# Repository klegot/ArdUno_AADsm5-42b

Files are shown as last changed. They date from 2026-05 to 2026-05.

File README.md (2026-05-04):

# Проектирование Arduino Uno в Altium Designer

Репозиторий содержит материалы учебного цикла из 8 лабораторных работ по курсу **«Конструирование приборов»**. В рамках проекта осуществляется воссоздание платы **Arduino Uno** с адаптацией под стандарты **ГОСТ/ЕСКД**.

## 🎯 Цель лабораторных работ
Пройти полный цикл проектирования электронного узла в САПР Altium Designer: от создания библиотек компонентов до генерации производственных файлов.

## 🛠 Технологический стек
* **САПР:** Altium Designer
* **Стандарты:** ГОСТ 2.701-2008, ГОСТ 2.106-1996
* **Компонентная база:** ATMEGA328P-PU и сопутствующая обвязка
---
*Работа выполнена в рамках учебного процесса МГТУ им. Н.Э. Баумана (кафедра СМ5).*

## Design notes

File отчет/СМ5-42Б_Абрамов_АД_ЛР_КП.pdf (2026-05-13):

Москва, 2026

Министерство науки и высшего образования Российской Федерации Федеральное государственное автономное образовательное учреждение высшего образования
«Московский государственный технический университет имени Н.Э. Баумана
(национальный исследовательский университет)» (МГТУ им. Н.Э. Баумана)
ФАКУЛЬТЕТ | Специальное машиностроение
КАФЕДРА | Автономные информационные и управляющие системы

### ОТЧЕТ ПО ЛАБОРАТОРНЫМ РАБОТАМ По курсу: «Конструирование приборов»

Группа: | СМ5-42б
Студент | Абрамов А.Д.
дата сдачи работы | подпись | фамилия, и.о.
Преподаватель | Воробьев А.К.
| подпись | фамилия, и.о.

### 1 Основные пункты выполнения работы

В рамках данного курса требуется создать проект, включающий схемную

библиотеку компонентов, библиотеку посадочных топологических мест

компонентов (ПТМ), электрическую принципиальную схему устройства,

трассировку печатной платы. Также создать выходную документацию для

производства (гербер-файлы, файлы сверловки, перечень элементов, 3D-модель

платы). Все действия проводятся в соответствии с ГОСТ, проект повторяет

Arduino Uno, порядок действий:

- Разработка библиотек компонентов: создание УГО и ПТМ

микросхемы ATMEGA328P-PU,

- Разработка библиотек компонентов: создание УГО и ПТМ

микросхемы ATMEGA16U2-MU,

- Разработка библиотек компонентов: создание УГО и ПТМ для

резистора, варистора, предохранителя, конденсатора, диода, светодиода и

кварцевого резонатора,

- Разработка библиотек компонентов: создание УГО и ПТМ для

разъемов, микросхемы ОУ, микросхемы линейного стабилизатора напряжения,

индуктивности, полевого транзистора и кнопочного переключателя,

- Создание электрической принципиальной схемы: подключение

форматки, отрисовка электрической принципиальной схемы, проверка схемы на

наличие ошибок, формирование перечня компонентов, экспорт схемы в PDF,

- Размещение компонентов на печатной плате: импорт компонентов на

ПП, задание геометрических размеров ПП, стадии размещения компонентов на

- ПП, размещение компонентов на ПП, 3D-вид ПП,
- Подготовка к трассировке печатной платы: настройка правил

проектирования, импорт/экспорт правил проектирования, настройка структуры

слоев ПП, настройка редактора ПП,

- Трассировка печатной платы: трассировка сигнальных линий,

трассировка питания и земли, заливка полигонов, оптимизация расположения проводников, отладка ошибок трассировки, установка реперных знаков,

формирования файлов для производства.

### 2 Создание проекта в Altium Designer и разработка библиотек

компонентов

В Altium Designer создан проект ArdUno_AADsm5-42b_ver1.1, в него

добавлены файлы схемной библиотеки, библиотеки посадочных мест, схемы и

печатной платы (Рисунок 1).

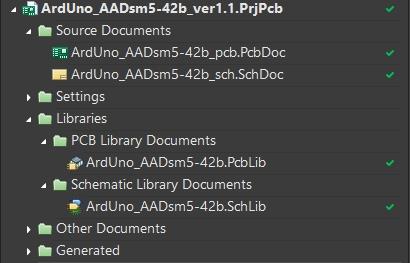
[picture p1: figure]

Рисунок 1 – Рабочая директория проекта и его содержание

В процессе проектирования и подготовки изделия к изготовлению для

каждого элемента необходимо создать несколько представлений: условное

графическое обозначение (УГО) и посадочное топологическое место (ПТМ) для

печатной платы (Footprint). ПТМ включает в себя конфигурацию контактных

площадок (КП) и контур корпуса детали с регламентированными габаритами,

которые берутся из технической документации (Datasheet) на конкретное

изделие. ПТМ задает точную область на плате, необходимую для установки,

фиксации и электрического подключения физического элемента. Алгоритм

создания посадочных мест продемонстрирован на примере базовой группы

компонентов, тогда как для остальных деталей операции выполняются по

аналогичной схеме.

Создано УГО микросхемы ATMEGA328P-PU. В файле схемной

библиотеки, в панели SCH Library добавлен новый компонент кнопкой Add.

Настроено окно свойств компонента (Рисунок 2), знак «?» в поле Designator

необходим Altium для последующей автоматической нумерации компонентов на

схеме, заданы соответствующие параметры создаваемого элемента.

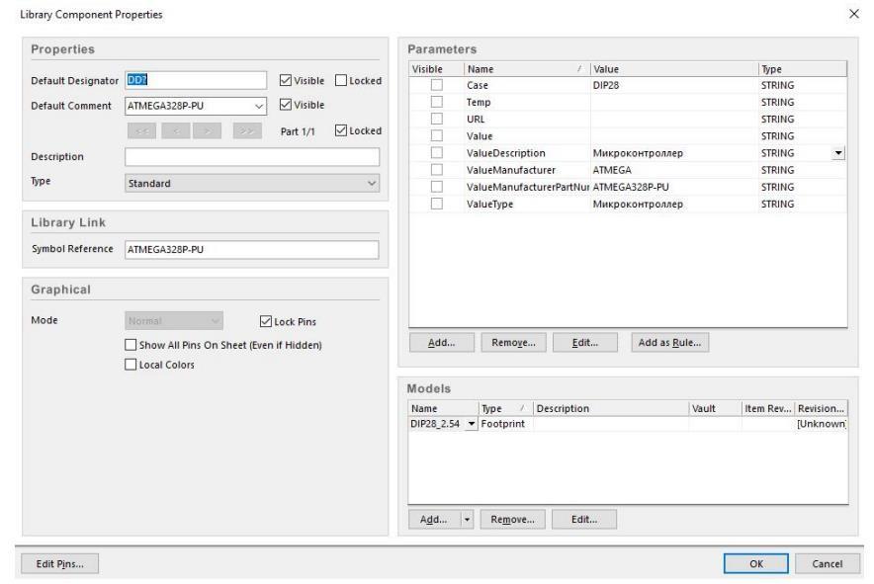
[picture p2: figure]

Рисунок 2 – Окно настройки свойств компонента схемной библиотеки

Начерчены границы корпуса в виде прямоугольника 50х135 мм и

вертикальные линии, отделяющие основное поле для подписей от двух

дополнительных, на расстоянии 10 мм друг от друга, затем размещены все 28

выводов микросхемы согласно документации, добавлены подписи (Рисунок 3).

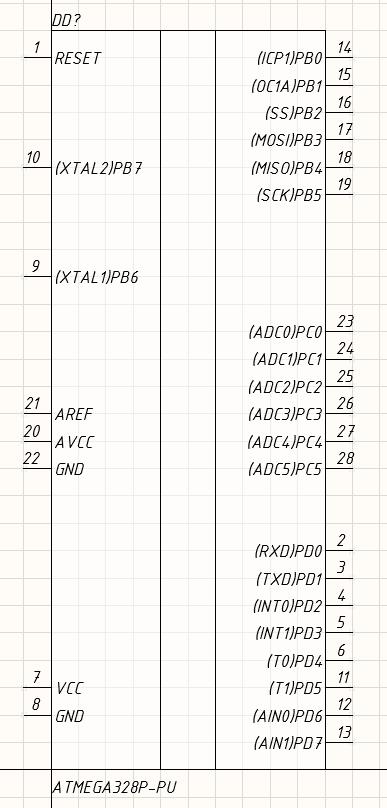
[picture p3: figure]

Рисунок 3 – УГО микросхемы ATMEGA328P-PU

Создано ПТМ микросхемы ATMEGA328P-PU в соответствии с

технической документацией (Рисунок 4) с помощью мастера создания ПТМ, где

выбраны параметры:

- тип корпуса: DIP,
- диаметр КП и отверстий: 1,8 мм и 1,1 мм соответственно,
- расположение КП: 7,62 мм между рядами и 2,54 мм между

элементами одного ряда,

- количество выводов: 28,
- имя создаваемого компонента: DIP28_2.54.

Рисунок 4 – Фрагмент datasheet микросхемы ATMEGA328P-PU с

геометрическими размерами

С помощью шелкографии заданы границы компонента и отмечено

положение 1 вывода микросхемы, результат работы представлен на Рисунке 5.

Рисунок 5 – ПТМ микросхемы ATMEGA328P-PU

Создание ПТМ завершено добавлением к нему 3D-модели корпуса

микросхемы (Рисунок 6).

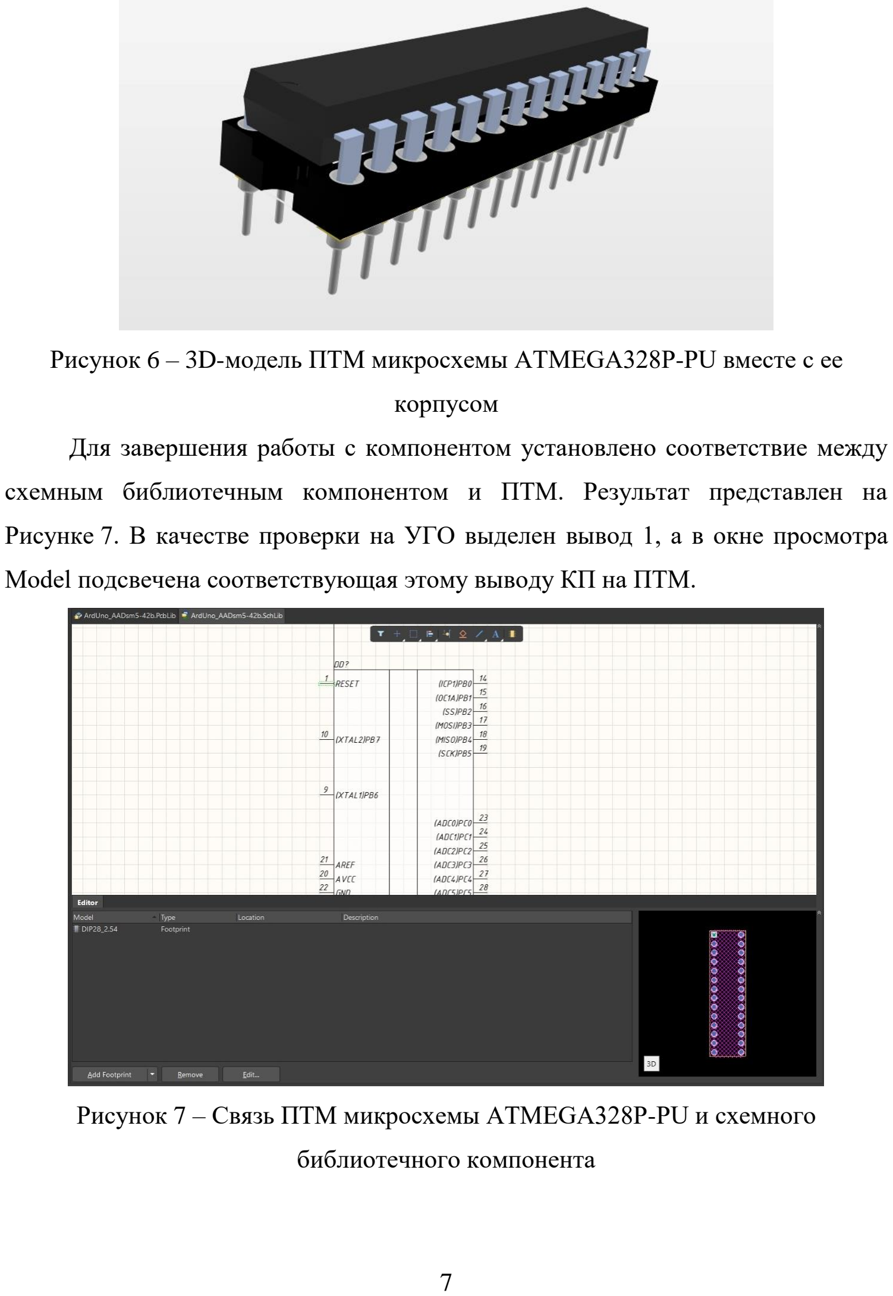
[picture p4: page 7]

Рисунок 6 – 3D-модель ПТМ микросхемы ATMEGA328P-PU вместе с ее

корпусом

Для завершения работы с компонентом установлено соответствие между

схемным библиотечным компонентом и ПТМ. Результат представлен на

Рисунке 7. В качестве проверки на УГО выделен вывод 1, а в окне просмотра

Model подсвечена соответствующая этому выводу КП на ПТМ.

Рисунок 7 – Связь ПТМ микросхемы ATMEGA328P-PU и схемного

библиотечного компонента

Создано УГО конденсатора в схемной библиотеке компонентов. Добавлен

новый компонент и его параметры аналогично предыдущему компоненту. Далее,

было начерчено УГО конденсатора, соответствующее УГО данному в журнале

Радио (№3, 2003 год, стр. 40), приведенное на Рисунке 8. Полученное УГО

конденсатора с добавленными двумя выводами приведено на Рисунке 9.

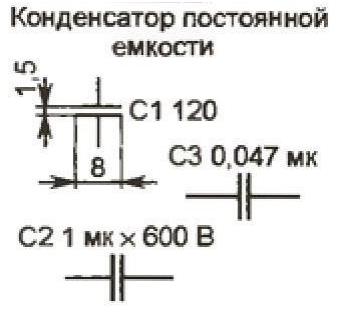
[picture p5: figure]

Рисунок 8 УГО конденсатора из журнала Радио (№3, 2003 год, стр. 40)

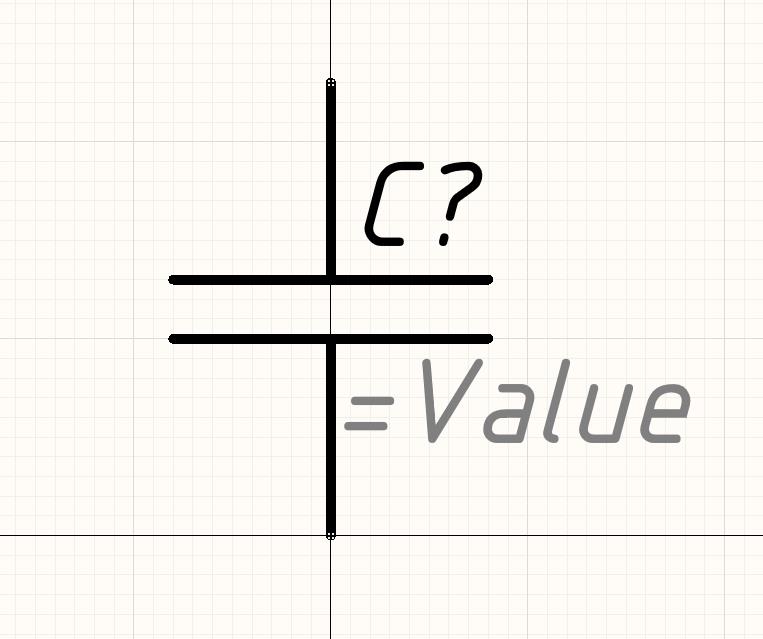
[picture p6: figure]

Рисунок 9 – УГО конденсатора

Создано ПТМ конденсатора. В проекте использован тип неполярных

конденсаторов SMD и типоразмер 0603, использованы параметры ПТМ для

пайки методом оплавления (Рисунок 10).

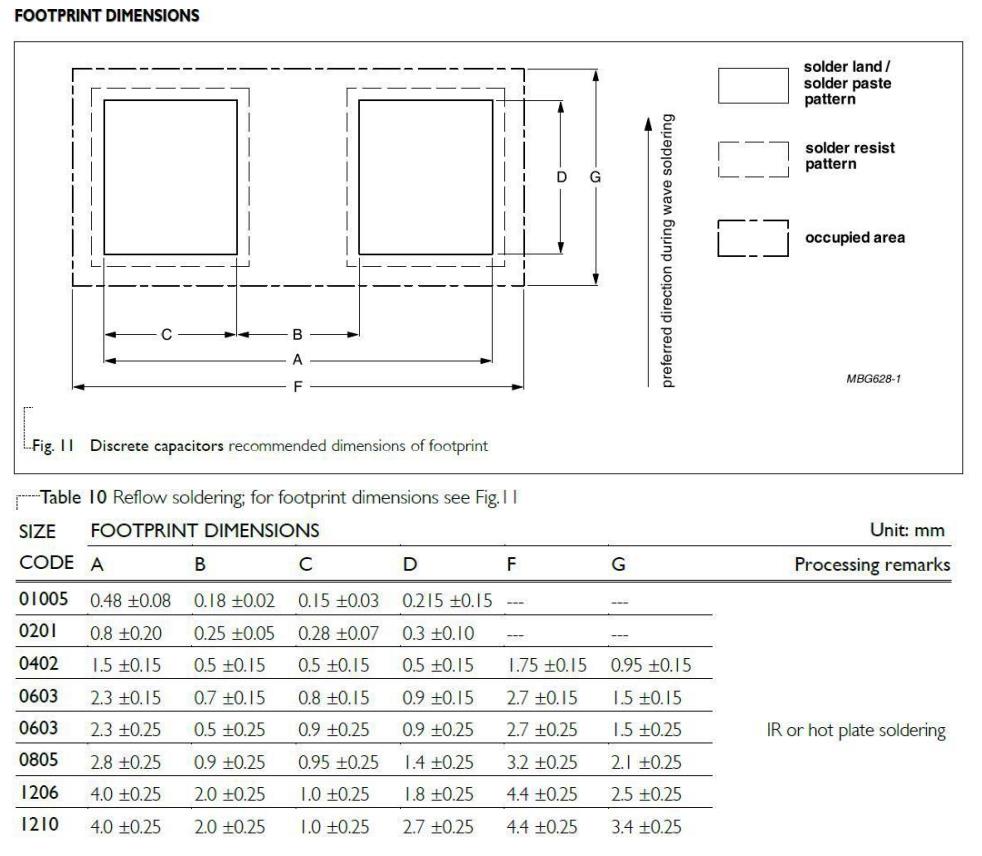
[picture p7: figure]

Рисунок 10 – Геометрические размеры ПТМ для SMD-конденсаторов

На слое Top Layer командой размещения КП Place – Pad размещены на

расстоянии 0,6 мм друг от друга две прямоугольные КП с параметрами

(Рисунок 11):

- размер КП: 0,8х0,9 мм,
- форма КП: Rectangular.

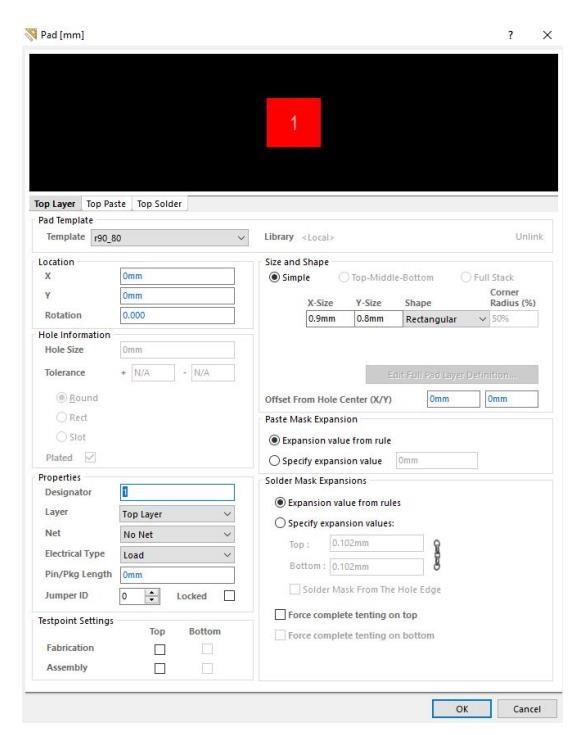
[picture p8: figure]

Рисунок 11 – Диалоговое окно Pad настройки параметров контактной площадки

С помощью шелкографии обозначено положение конденсатора. Результат

создания ПТМ конденсатора представлен на Рисунке 12.

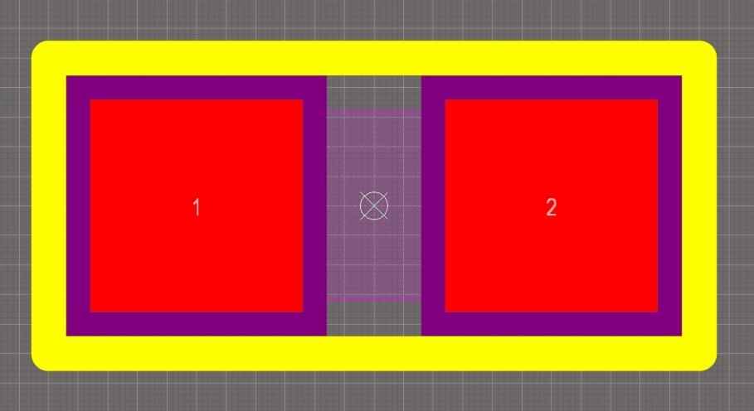
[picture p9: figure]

Рисунок 12 – ПТМ конденсатора

К ПТМ конденсатора прикреплена его 3D-модель (Рисунок 13).

Рисунок 13 – 3D-модель конденсатора на его ПТМ

Установлено соответствие между созданным схемным библиотечным

компонентом и ПТМ конденсатора (Рисунок 14). Аналогично проверена

привязка выводов.

Рисунок 14 – Связь ПТМ конденсатора и схемного библиотечного компонента

### 3 Создание электрической принципиальной схемы и перечня

элементов

На | основании | разработанной | библиотеки | схемных | компонентов

разработана электрическая принципиальная схема устройства Arduino Uno в соответствии с предложенным примером (Рисунок А.1). Размещены компоненты

из схемной библиотеки, выполнены электрические соединения между ними с

помощью команды Place – Wire. Добавлены порты питания и земли с помощью

команды Place – Power Port, затем последние соединены с соответствующими

выводами компонентов, параметры портов настроены в соответствии с ГОСТ

(Рисунки 15, 16).

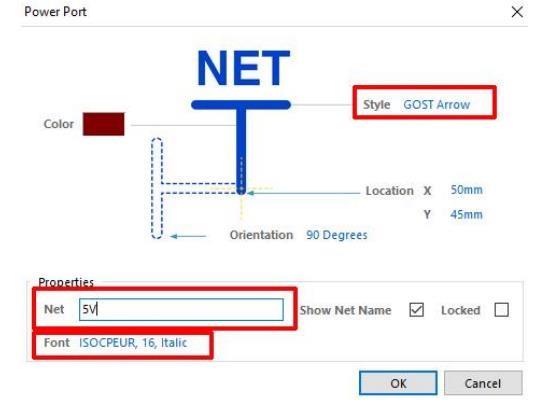
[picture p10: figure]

Рисунок 15 – Диалоговое окно Power Port

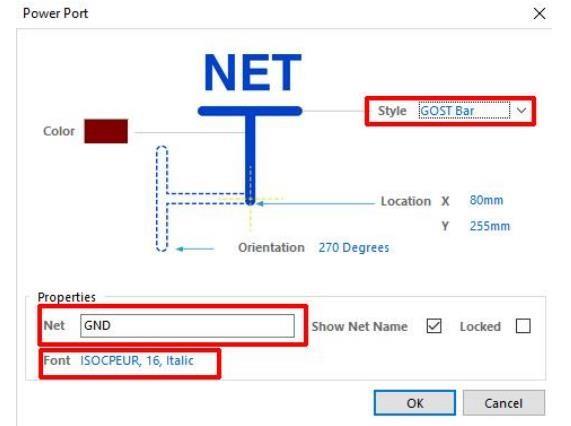
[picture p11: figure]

Рисунок 16 – Диалоговое окно Power Port

После отрисовки электрической принципиальной схемы проведена

нумерация компонентов на схеме с помощью команды Annotate Schematics

(Рисунок 17), схема проверена на наличие ошибок.

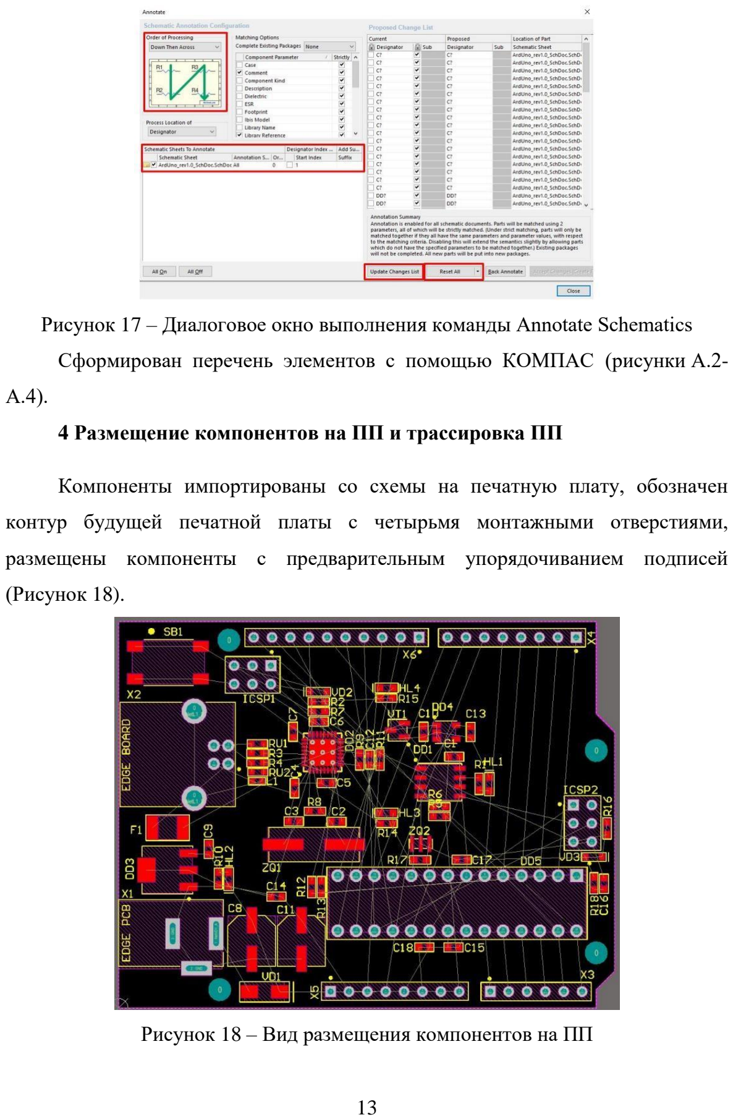
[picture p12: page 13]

Рисунок 17 – Диалоговое окно выполнения команды Annotate Schematics

Сформирован перечень элементов с помощью КОМПАС (рисунки А.2-

А.4).

### 4 Размещение компонентов на ПП и трассировка ПП

Компоненты импортированы со схемы на печатную плату, обозначен

контур будущей печатной платы с четырьмя монтажными отверстиями,

размещены компоненты с предварительным упорядочиванием подписей

(Рисунок 18).

Рисунок 18 – Вид размещения компонентов на ПП

Настроены правила проектирования в соответствии с допустимыми

технологическими возможностями производства, структура слоев, редактор ПП.

Произведена трассировка печатной платы. Все КП, имеющие соединение с

цепью GND соединены с переходными отверстиями, пример приведен на

Рисунке 19.

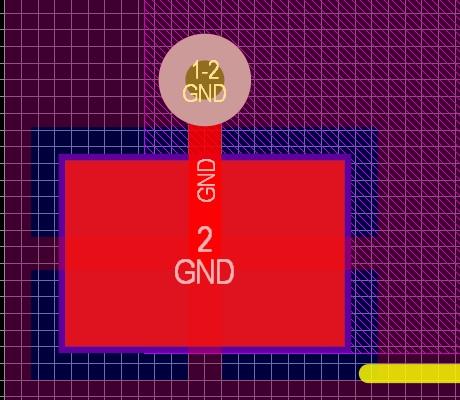
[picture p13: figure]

Рисунок 19 – Размещение переходного отверстия и соединение его с КП

Произведена трассировка длинных сигнальных проводников, коротких

сигнальных проводников, линий питания (ширина проводника увеличена), затем

созданы полигоны земли. С помощью инструмента Design Rule Check

осуществлена проверка топологии ПП, исправлены выявленные ошибки.

Оптимизированы | области | полигонов, | расширено | их | перекрытие, | на

соответствующих участках поставлены переходные отверстия, затем последние

установлены везде, где земляные полигоны верхнего и нижнего слоев

перекрываются (после этого полигоны перезалиты). С помощью инструмента

Design Rule Check снова проведена проверка, исправлены все выявленные

ошибки (Рисунок 20), установлены реперные знаки.

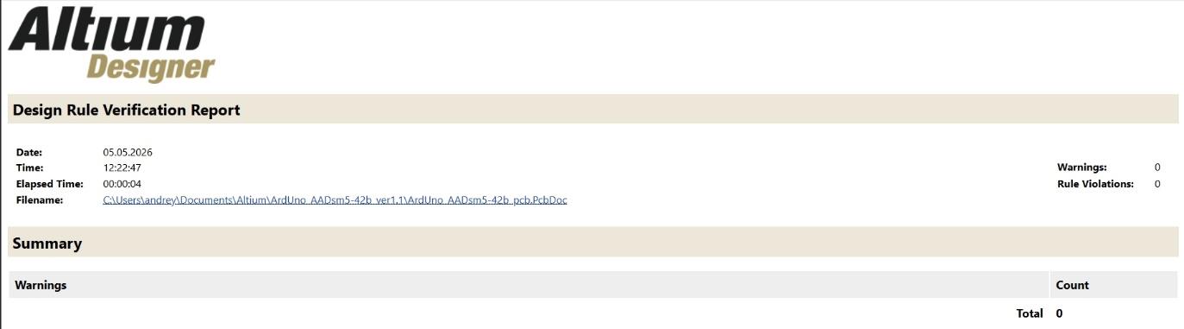
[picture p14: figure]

Рисунок 20 – Отсутствие ошибок проектирования

Оптимизировано | расположение | подписей | компонентов | на | слое

шелкографии, добавлено имя проекта на ПП. В результате проектирования

получена послойная структура печатной платы:

- Top Layer (Рисунок А.5),
- Top Solder (Рисунок А.6),
- Top Overlay (Рисунок А.7),
- Bottom Layer (Рисунок А.8), – Bottom Solder (Рисунок А.9),
- Keep Out Layer (Рисунок А.10).
Для | полного | представления | на | рисунках А.11-А.13 | содержатся

трехмерные изображения разработанной ПП.

Сформированы файлы сверловки (Рисунок А.14) и гербер-файлы

(Рисунки А.15-А.20) для производства.

Таким образом, в рамках учебного проектирования модуля Arduino Uno

были освоены ключевые инструменты среды Altium Designer. Пройден полный

цикл разработки печатной платы, включивший в себя формирование библиотек

компонентов (создание УГО и ПТМ согласно техническим требованиям),

настройку технологических ограничений под требования производства, а также

компоновку элементов на плате. Итогом работы стал завершенный проект

устройства, дополненный файлами для изготовления ПП и комплектом

конструкторской документации по ГОСТ (электрической принципиальной

схемой и перечнем элементов).

ПРИЛОЖЕНИЕ А

В приложение входят:

1) схема электрическая принципиальная (Рисунок А.1);
2) перечень элементов (Рисунки А.2-А.4);
3) послойная структура печатной платы (Рисунки А.5-А.10);
4) трехмерные изображения печатной платы (Рисунки А.11-А.13);
5) файлы сверловки (Рисунок А.14);
6) гербер-файлы (Рисунки А.15-А.20).

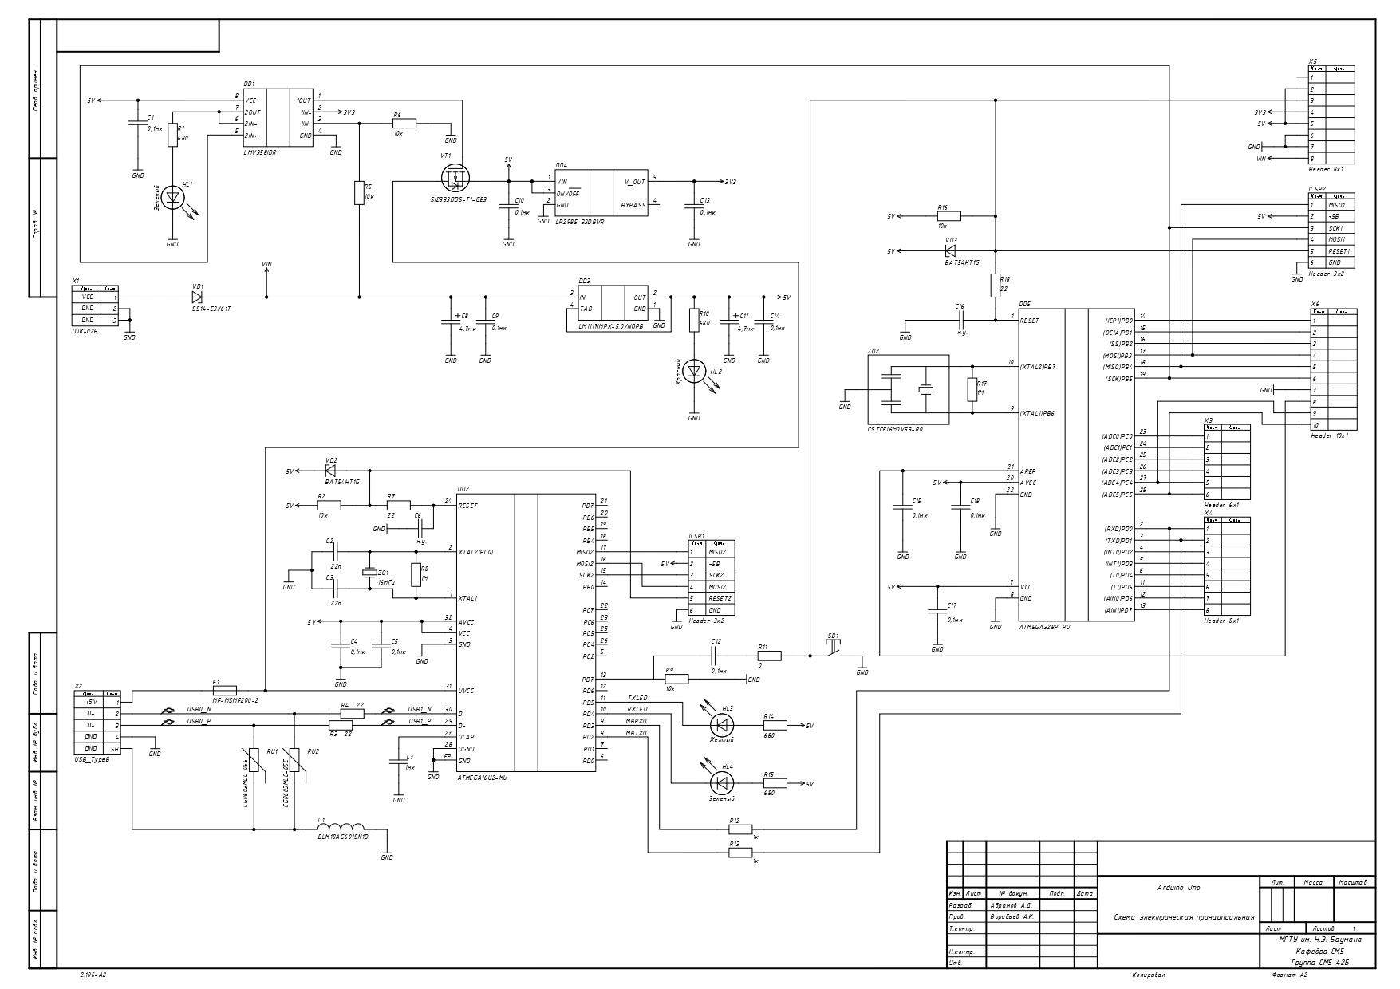
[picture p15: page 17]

Рисунок А.1 – Схема электрическая принципиальная

Москва, 2025 г.

Рисунок А.2 – Перечень элементов, лист 1

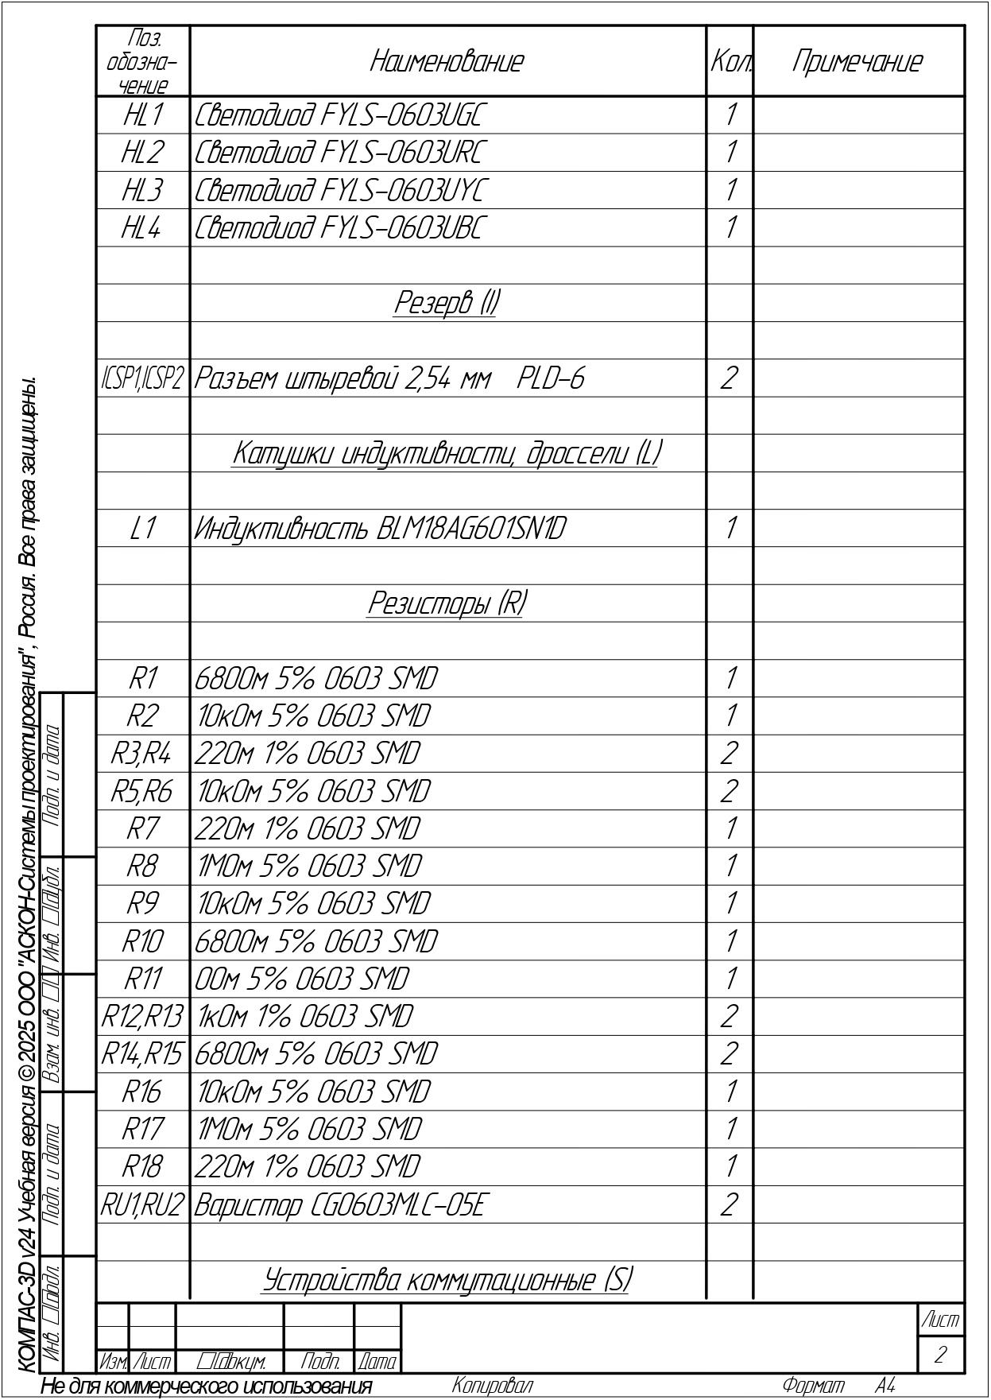
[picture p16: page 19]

Рисунок А.3 – Перечень элементов, лист 2

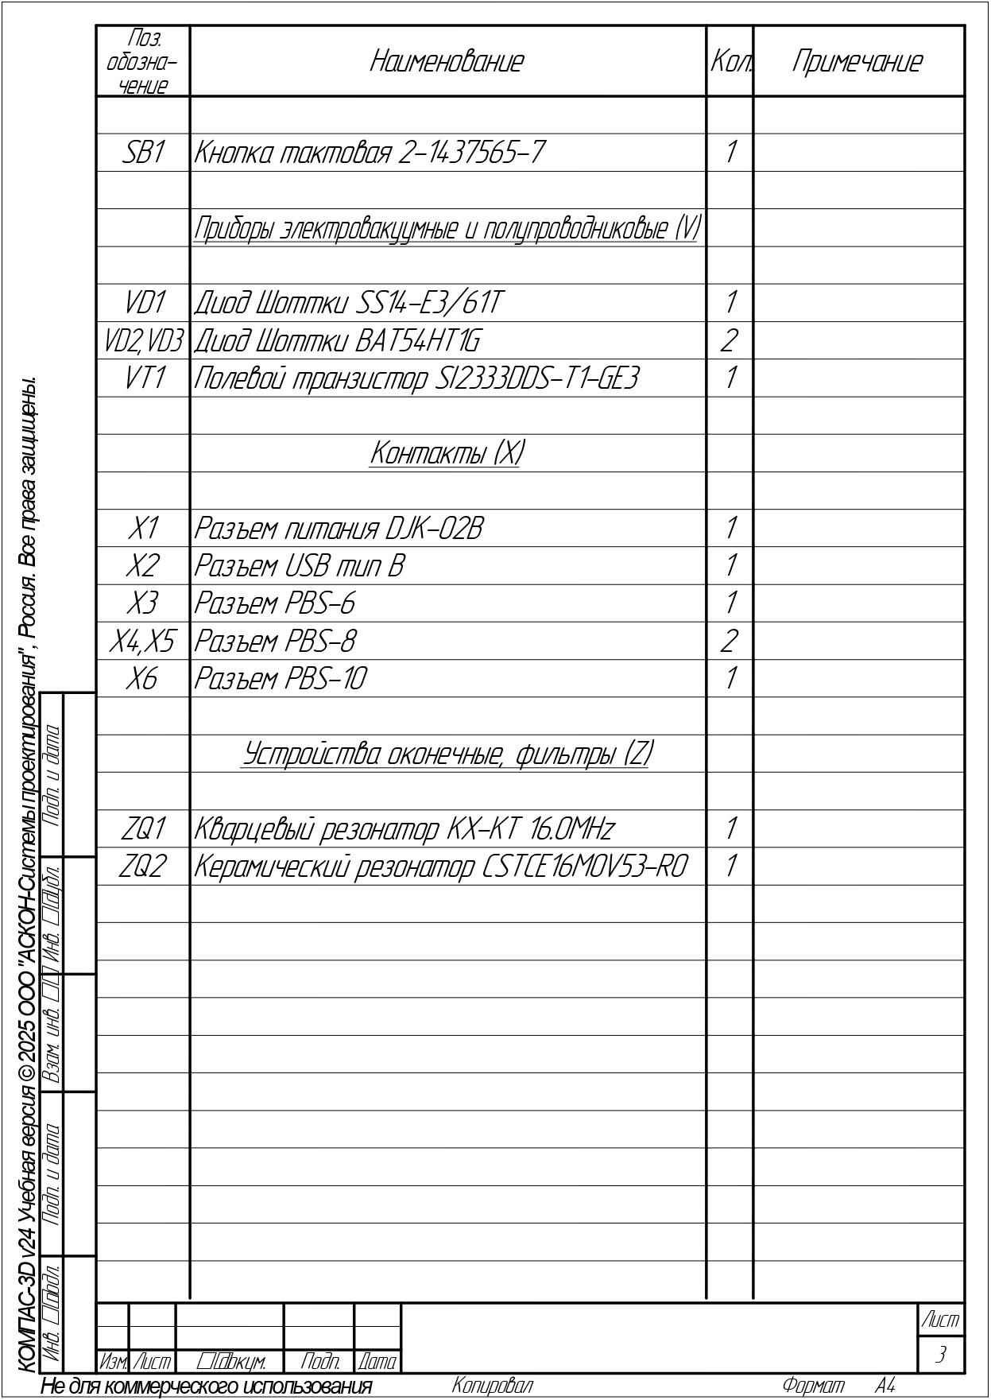
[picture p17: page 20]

Рисунок А.4 – Перечень элементов, лист 3

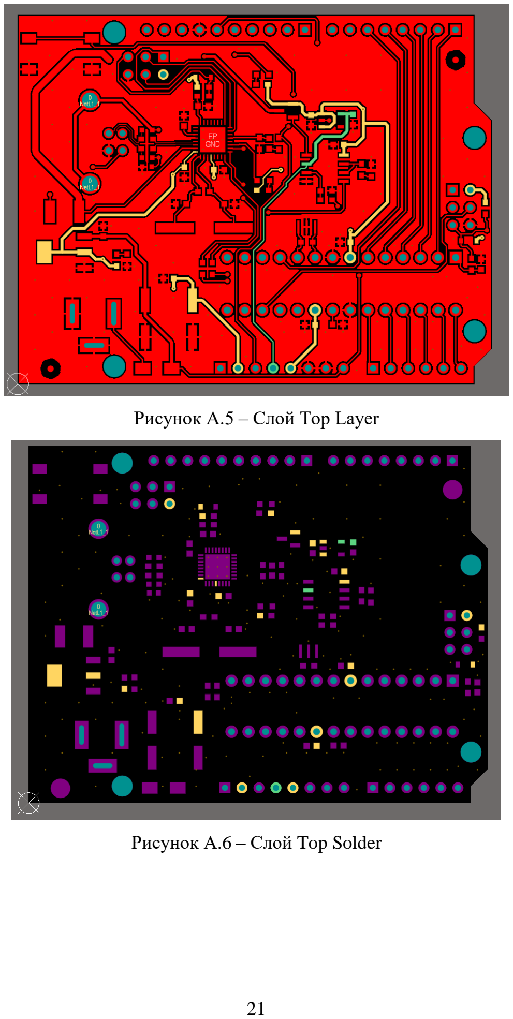
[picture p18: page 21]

Рисунок А.5 – Слой Top Layer

Рисунок А.6 – Слой Top Solder

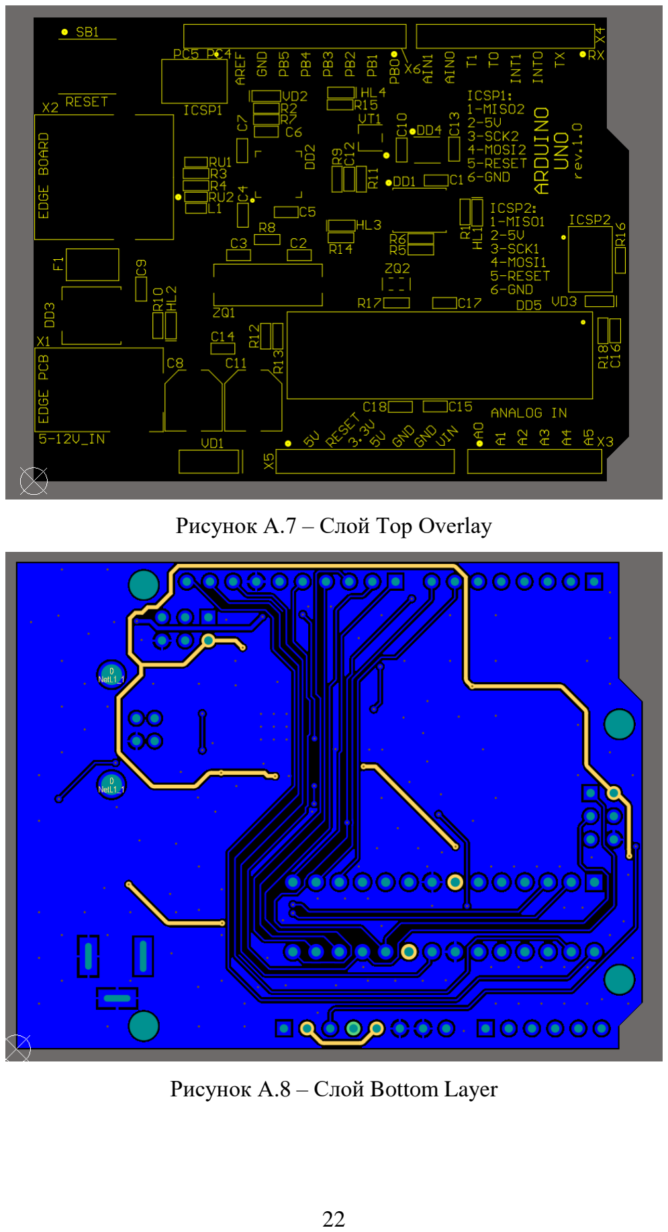
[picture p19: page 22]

Рисунок А.7 – Слой Top Overlay

Рисунок А.8 – Слой Bottom Layer

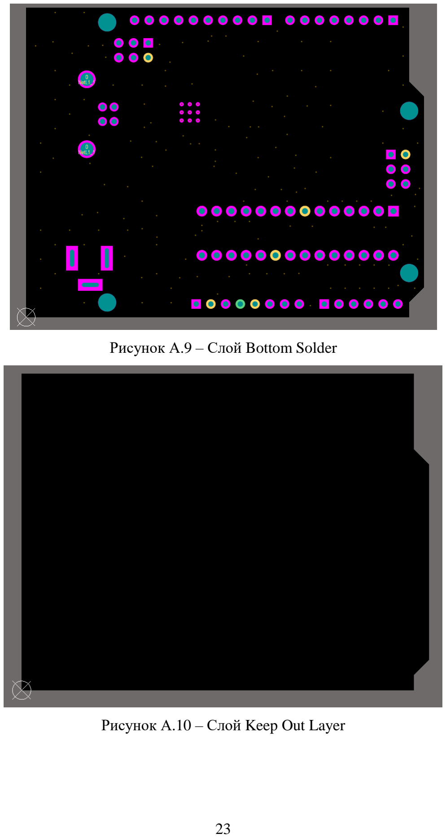
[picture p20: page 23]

Рисунок А.9 – Слой Bottom Solder

Рисунок А.10 – Слой Keep Out Layer

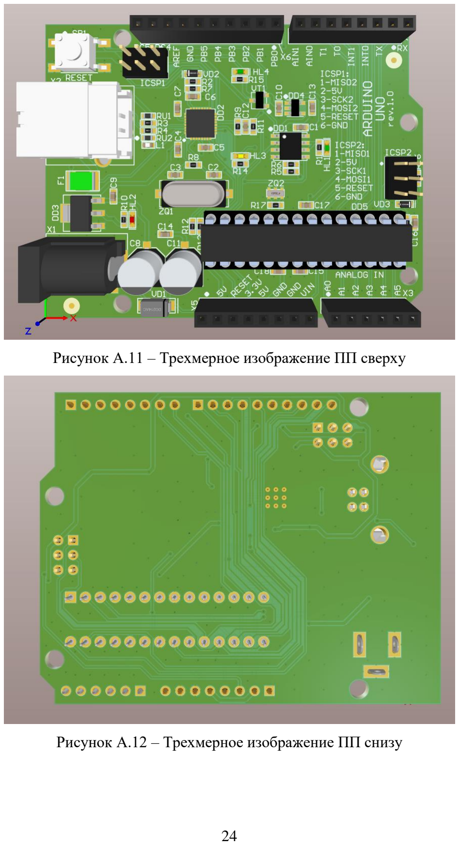
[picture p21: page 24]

Рисунок А.11 – Трехмерное изображение ПП сверху

Рисунок А.12 – Трехмерное изображение ПП снизу

Рисунок А.13 – Трехмерное изображение ПП сбоку

Рисунок А.14 – Файлы сверловки

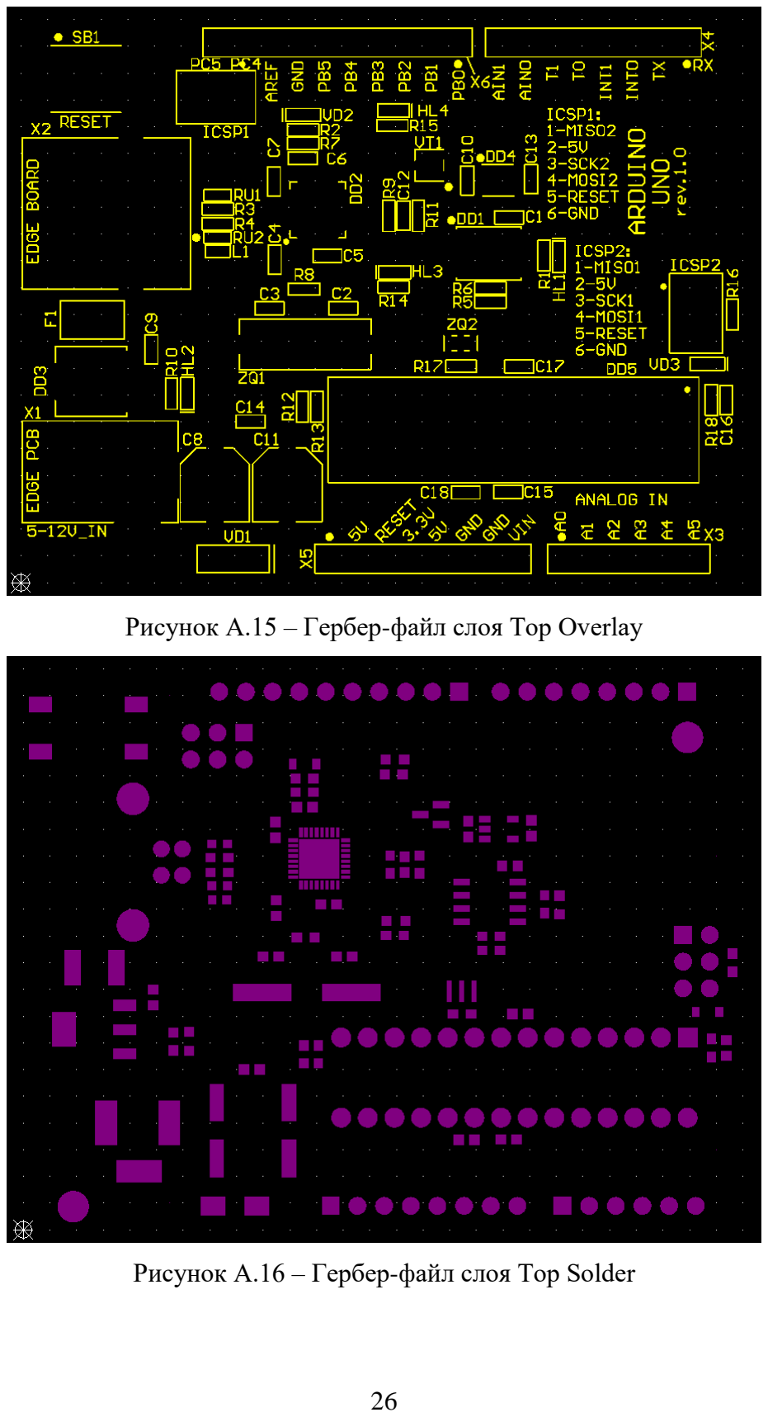
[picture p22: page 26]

Рисунок А.15 – Гербер-файл слоя Top Overlay

Рисунок А.16 – Гербер-файл слоя Top Solder

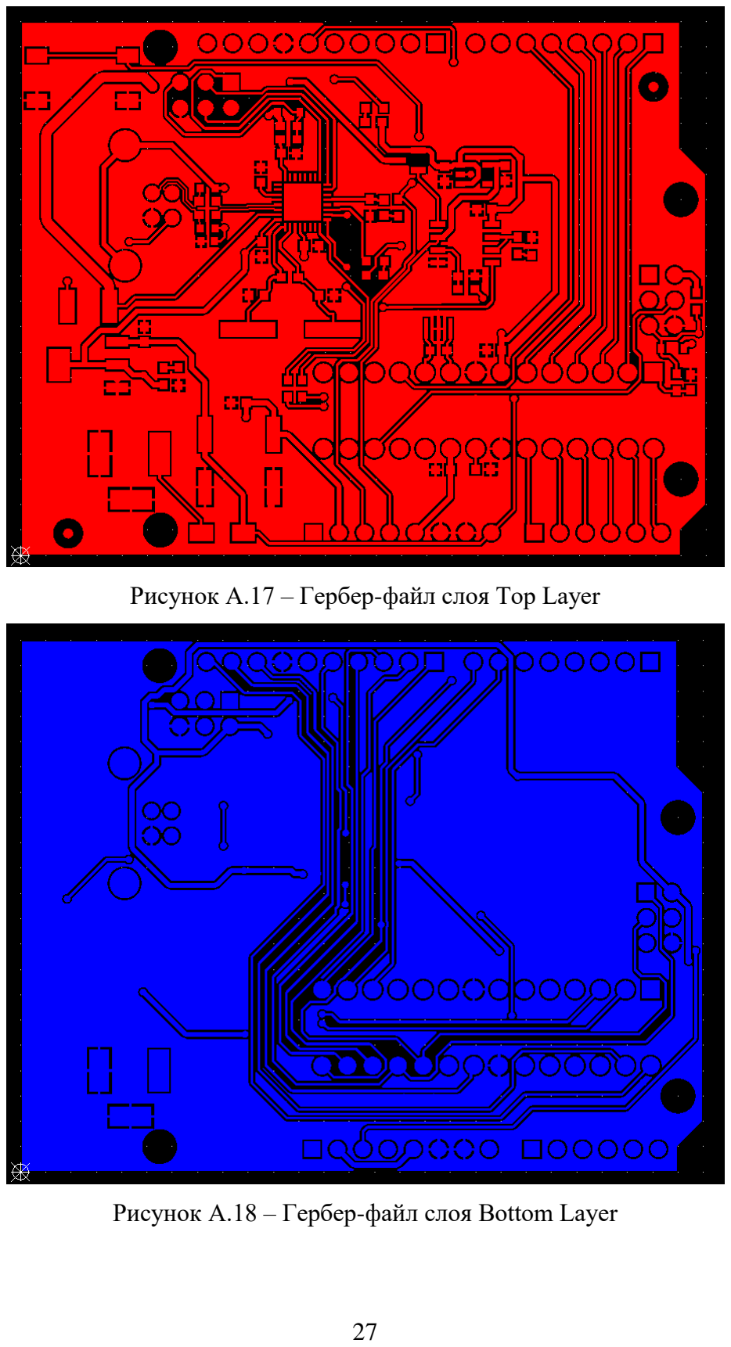
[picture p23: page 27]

Рисунок А.17 – Гербер-файл слоя Top Layer

Рисунок А.18 – Гербер-файл слоя Bottom Layer

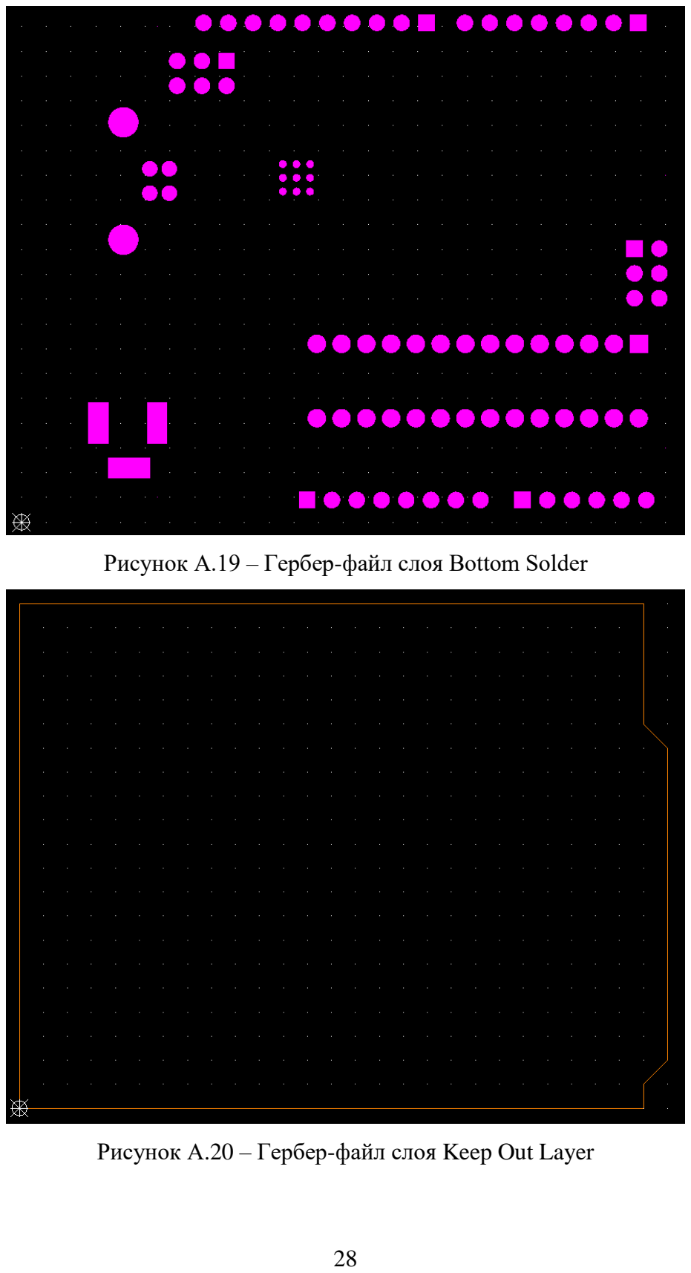
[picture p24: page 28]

Рисунок А.19 – Гербер-файл слоя Bottom Solder

Рисунок А.20 – Гербер-файл слоя Keep Out Layer

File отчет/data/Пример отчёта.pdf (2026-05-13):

### 1 Основные пункты выполнения работы

В рамках данного курса требуется создать проект, включающий схемную

библиотеку компонентов, библиотеку посадочных топологических мест компо-

нентов (ПТМ), электрическую принципиальную схему устройства, трассировку

печатной платы. Также создать выходную документацию для производства (гер-

бер-файлы, файлы сверловки, перечень элементов, 3D-модель платы). Все дей-

ствия проводятся в соответствии с ГОСТ, проект повторяет Arduino Uno, поря-

док действий:

– Разработка библиотек компонентов: создание УГО и ПТМ микросхемы

ATMEGA328P-PU,

– Разработка библиотек компонентов: создание УГО и ПТМ микросхемы

ATMEGA16U2-MU,

– Разработка библиотек компонентов: создание УГО и ПТМ для резистора,

варистора, предохранителя, конденсатора, диода, светодиода и кварцевого резо-

натора,

– Разработка библиотек компонентов: создание УГО и ПТМ для разъемов,

микросхемы ОУ, микросхемы линейного стабилизатора напряжения, индуктив-

ности, полевого транзистора и кнопочного переключателя,

– Создание электрической принципиальной схемы: подключение фор-

матки, отрисовка электрической принципиальной схемы, проверка схемы на

наличие ошибок, формирование перечня компонентов, экспорт схемы в PDF,

– Размещение компонентов на печатной плате: импорт компонентов на

ПП, задание геометрических размеров ПП, стадии размещения компонентов на

ПП, размещение компонентов на ПП, 3D-вид ПП,

– Подготовка к трассировке печатной платы: настройка правил проектиро-

вания, импорт/экспорт правил проектирования, настройка структуры слоев ПП,

настройка редактора ПП,

– Трассировка печатной платы: трассировка сигнальных линий, трасси-

ровка питания и земли, заливка полигонов, оптимизация расположения проводников, отладка ошибок трассировки, установка реперных знаков, форми-

рования файлов для производства.

### 2 Создание проекта в Altium Designer и разработка библиотек

компонентов

В Altium Designer создан проект ArdUno_TDAsm5-61_ver1.1, в него добав-

лены файлы схемной библиотеки, библиотеки посадочных мест, схемы и печат-

ной платы (рисунок 1).


Рисунок 1 – Проект и его содержание

При разработке и подготовке к производству проекта каждый компонент

нуждается в различных представлениях: условное графическое обозначение

(УГО), посадочное топологическое место (ПТМ) на плате (Footprint). ПТМ со-

держит набор контактных площадок (КП) на плате и изображение корпуса ком-

понента с жестко фиксированными размерами, определяемыми технической до-

кументацией на используемый компонент. ПТМ определяет часть платы, требу-

емую для монтажа и подсоединения физического компонента на плате. Процесс

разработки последних рассмотрен на примере нескольких компонентов, для дру-

гих элементов последовательность действий аналогична.

Создано УГО микросхемы ATMEGA328P-PU. В файле схемной библио-

теки, в панели SCH Library добавлен новый компонент кнопкой Add. Настроено

окно свойств компонента (рисунок 2), знак «?» в поле Designator необходим

Altium для последующей автоматической нумерации компонентов на схеме, за-

даны соответствующие параметры создаваемого элемента.


Рисунок 2 – Окно настройки свойств компонента схемной библиотеки

Начерчены границы корпуса в виде прямоугольника 50х135 мм и верти-

кальные линии, отделяющие основное поле для подписей от двух дополнитель-

ных, на расстоянии 10 мм друг от друга, затем размещены все 28 выводов мик-

росхемы согласно документации, добавлены подписи (рисунок 3).


Рисунок 3 – УГО микросхемы ATMEGA328P-PU

Создано ПТМ микросхемы ATMEGA328P-PU в соответствии с техниче-

ской документацией (рисунок 4) с помощью мастера создания ПТМ, где вы-

браны параметры:

– тип корпуса: DIP,

– диаметр КП и отверстий: 1,8 мм и 1,1 мм соответственно,

– расположение КП: 7,62 мм между рядами и 2,54 мм между элементами

одного ряда,

– количество выводов: 28,

– имя создаваемого компонента: DIP28_2.54.

Рисунок 4 – Фрагмент datasheet микросхемы ATMEGA328P-PU с

геометрическими размерами

С помощью шелкографии заданы границы компонента и отмечено поло-

жение 1 вывода микросхемы, результат работы представлен на рисунке 5.

Рисунок 5 – ПТМ микросхемы ATMEGA328P-PU


Создание ПТМ завершено добавлением к нему 3D-модели корпуса микро-

схемы (рисунок 6).

Рисунок 6 – 3D-модель ПТМ микросхемы ATMEGA328P-PU вместе с ее

корпусом

Для завершения работы с компонентом установлено соответствие между

схемным библиотечным компонентом и ПТМ. Результат представлен на рисунке

7. В качестве проверки на УГО выделен вывод 10, а в окне просмотра Models

подсвечена соответствующая этому выводу КП на ПТМ.

Рисунок 7 – Связь ПТМ микросхемы ATMEGA328P-PU и схемного

библиотечного компонента

Создано УГО резистора в схемной библиотеке компонентов. Добавлен но-

вый компонент и его параметры аналогично предыдущему компоненту. Начер-

чен прямоугольник размерами 4х10 мм, добавлены подписи, затем добавлены 2

вывода резистора (рисунок 8).

Рисунок 8 – УГО резистора

Создано ПТМ резистора. В проекте использован тип резисторов SMD и ти-

поразмер 0603, использованы параметры ПТМ для пайки методом оплавления

(рисунок 9).


Рисунок 9 – Геометрические размеры ПТМ для SMD-резисторов

На слое Top Layer командой размещения КП Place – Pad размещены на

расстоянии 0,8 мм друг от друга две прямоугольные КП с параметрами (рисунок

10):

– размер КП: 0,9х0,8 мм,

– форма КП: Rectangular.


Рисунок 10 – Диалоговое окно Pad настройки параметров контактной площадки

В дальнейшем возможности этого диалогового окна использованы для со-

здания ПТМ, в которых КП похожи на использованные для микросхемы AT-

MEGA328P-PU, но в которых требуется меньше КП, и они имеют разное распо-

ложение и размеры (например, разъемы питания и USB), это можно будет уви-

деть на слоях спроектированной ПП.

С помощью шелкографии обозначено положение резистора. Результат со-

здания ПТМ резистора представлен на рисунке 11.


Рисунок 11 – ПТМ резистора

К ПТМ резистора прикреплена его 3D-модель (рисунок 12).

Рисунок 12 – 3D-модель резистора на его ПТМ

Установлено соответствие между созданным схемным библиотечным ком-

понентом и ПТМ резистора (рисунок 13). Аналогично проверена привязка выво-

дов.


Рисунок 13 – Связь ПТМ резистора и схемного библиотечного компонента

### 3 Создание электрической принципиальной схемы и перечня

элементов

На основании разработанной библиотеки схемных компонентов разрабо-

тана электрическая принципиальная схема устройства Arduino Uno в соответ-

ствии с предложенным примером (рисунок А.1). Размещены компоненты из

схемной библиотеки, выполнены электрические соединения между ними с помо-

щью команды Place – Wire. Добавлены порты питания и земли с помощью ко-

манды Place – Power Port, затем последние соединены с соответствующими выводами компонентов, параметры портов настроены в соответствии с ГОСТ

(рисунки 14, 15).


Рисунок 14 – Диалоговое окно Power Port


Рисунок 15 – Диалоговое окно Power Port

После отрисовки электрической принципиальной схемы проведена нуме-

рация компонентов на схеме с помощью команды Annotate Schematics (рисунок

16), схема проверена на наличие ошибок.


Рисунок 16 – Диалоговое окно выполнения команды Annotate Schematics

Сформирован перечень элементов с помощью КОМПАС (рисунки А.2-

А.4).

### 4 Размещение компонентов на ПП и трассировка ПП

Компоненты импортированы со схемы на печатную плату, обозначен кон-

тур будущей печатной платы с четырьмя монтажными отверстиями, размещены

компоненты с предварительным упорядочиванием подписей (рисунок 17).


Рисунок 17 – Вид размещения компонентов на ПП

Настроены правила проектирования в соответствии с допустимыми техно-

логическими возможностями производства, структура слоев, редактор ПП.

Произведена трассировка печатной платы. Все КП, имеющие соединение

с цепью GND соединены с переходными отверстиями, пример приведен на ри-

сунке 18.

Рисунок 18 – Размещение переходного отверстия и соединение его с КП

Произведена трассировка длинных сигнальных проводников, коротких

сигнальных проводников, линий питания (ширина проводника увеличена), затем

созданы полигоны земли, с помощью инструмента Design Rule Check осуществ-

лена проверка топологии ПП, исправлены выявленные ошибки. Оптимизиро-

ваны области полигонов, расширено их перекрытие, на соответствующих участ-

ках поставлены переходные отверстия, затем последние установлены везде, где

земляные полигоны верхнего и нижнего слоев перекрываются (после этого по-

лигоны перезалиты). С помощью инструмента Design Rule Check снова прове-

дена проверка, исправлены все выявленные ошибки (рисунок 19), установлены

реперные знаки.

Рисунок 19 – Отсутствие ошибок проектирования

Оптимизировано расположение подписей компонентов на слое шелкогра-

фии, добавлено имя проекта на ПП. В результате проектирования получена по-

слойная структура печатной платы:

– Top Layer (рисунок А.5),

– Top Solder (рисунок А.6),

– Top Overlay (рисунок А.7),

– Bottom Layer (рисунок А.8),

– Bottom Solder (рисунок А.9),

– Keep Out Layer (рисунок А.10).

Для полного представления на рисунках А.11-А.13 содержатся трехмерные

изображения разработанной ПП.

Сформированы файлы сверловки (рисунок А.14) и гербер-файлы (рисунки

А.15-А.20) для производства.

Таким образом, в ходе учебного проектирования заранее заданного модуля

Arduino Uno были изучены все основные возможности Altium Designer. Кроме

того, полностью пройден процесс проектирования печатной платы, который,

включил в себя создание библиотеки компонентов (УГО и ПТМ с учетом технических требований), настройку правил проектирования на основании воз-

можностей производства, размещение компонентов на ПП. В результате получен

готовый проект печатной платы в комплекте с файлами для производства и тех-

нической документацией по ГОСТ (схема электрическая принципиальная и пе-

речень элементов).

ПРИЛОЖЕНИЕ А

В приложение входят:

1) схема электрическая принципиальная (рисунок А.1);
2) перечень элементов (рисунки А.2-А.4);
3) послойная структура печатной платы (рисунки А.5-А.10);
4) трехмерные изображения печатной платы (А.11-А.13);
5) файлы сверловки (рисунок А.14);
6) гербер-файлы (рисунки А.15-А.20).


Рисунок А.1 – Схема электрическая принципиальная


Рисунок А.2 – Перечень элементов, лист 1


Рисунок А.3 – Перечень элементов, лист 2


Рисунок А.4 – Перечень элементов, лист 3


Рисунок А.5 – Слой Top Layer

Рисунок А.6 – Слой Top Solder


Рисунок А.7 – Слой Top Overlay

Рисунок А.8 – Слой Bottom Layer


Рисунок А.9 – Слой Bottom Solder

Рисунок А.10 – Слой Keep Out Layer


Рисунок А.11 – Трехмерное изображение ПП сверху

Рисунок А.12 – Трехмерное изображение ПП снизу


Рисунок А.13 – Трехмерное изображение ПП сбоку

Рисунок А.14 – Файлы сверловки


Рисунок А.15 – Гербер-файл слоя Top Overlay

Рисунок А.16 – Гербер-файл слоя Top Solder


Рисунок А.17 – Гербер-файл слоя Top Layer

Рисунок А.18 – Гербер-файл слоя Bottom Layer


Рисунок А.19 – Гербер-файл слоя Bottom Solder

Рисунок А.20 – Гербер-файл слоя Keep Out Layer

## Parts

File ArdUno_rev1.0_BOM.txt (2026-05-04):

Designator	ValueType	ValueDescription	ValueManufacturerPartNumber	ValueManufacturer	Quantity

"C1, C4, C5, C9, C10, C12, C13, C14, C15, C17, C18"	"Конденсатор"	"0,1мкФ  X7R 10% 0603 SMD"	""	""	"11"
"C2, C3"	"Конденсатор"	"22nФ  NP0 5% 0603 SMD"	""	""	"2"
"C6, C16"	"Конденсатор"	"н.у."	""	""	"2"
"C7"	"Конденсатор"	"1мкФ  X7R 10% 0603 SMD"	""	""	"1"
"C8, C11"	"Конденсатор"	"4,7мкФ   20% 0607 SMD"	""	""	"2"
"DD1"	"Операционный усилитель"	"Операционный усилитель"	"LMV358IDR"	"Texas Instruments"	"1"
"DD2"	"Микроконтроллер"	"Микроконтроллер"	"ATMEGA16U2-MU"	"ATMEGA"	"1"
"DD3"	"Линейный стабилизатор напряжения"	"Линейный стабилизатор напряжения"	"LM1117IMPX-5.0"	"Texas Instruments"	"1"
"DD4"	"Линейный стабилизатор напряжения"	"Линейный стабилизатор напряжения"	"LP2985-33DBVR"	"Texas Instruments"	"1"
"DD5"	"Микроконтроллер"	"Микроконтроллер"	"ATMEGA328P-PU"	"ATMEGA"	"1"
"F1"	"Предохранитель"	"Предохранитель"	"MF-MSMF200-2"	""	"1"
"HL1, HL4"	"Светодиод"	"Светодиод"	"FYLS-0603UGC"	"Foryard"	"2"
"HL2"	"Светодиод"	"Светодиод"	"FYLS-0603URC "	"Foryard"	"1"
"HL3"	"Светодиод"	"Светодиод"	"FYLS-0603UYC"	"Foryard"	"1"
"ICSP1, ICSP2"	"Разъем штыревой 2,54 мм"	"Разъем штыревой 2,54 мм  Разъем штыревой 2,54 мм  "	"PLD-6"	""	"2"
"L1"	"Индуктивность"	"Индуктивность"	"BLM18AG601SN1D"	""	"1"
"R1, R10, R14, R15"	"Резистор"	"680Ом 5% 0603 SMD"	""	""	"4"
"R2, R5, R6, R9, R16"	"Резистор"	"10кОм 5% 0603 SMD"	""	""	"5"
"R3, R4, R7, R18"	"Резистор"	"22Ом 1% 0603 SMD"	""	""	"4"
"R8, R17"	"Резистор"	"1МОм 5% 0603 SMD"	""	""	"2"
"R11"	"Резистор"	"0Ом 5% 0603 SMD"	""	""	"1"
"R12, R13"	"Резистор"	"1кОм 1% 0603 SMD"	""	""	"2"
"RU1, RU2"	"Варистор"	"Варистор"	"CG0603MLC-05E"	""	"2"
"SB1"	"Кнопка тактовая"	"Кнопка тактовая"	"2-1437565-7"	"Te Connectivity"	"1"
"VD1"	"Диод Шоттки"	"Диод Шоттки"	"SS14-E3/61T"	"Vishay"	"1"
"VD2, VD3"	"Диод Шоттки"	"Диод Шоттки"	"BAT54HT1G"	"On Semiconductor"	"2"
"VT1"	"MOSFET"	"Полевой транзистор"	"SI2333DDS-T1-GE3"	"Vishay"	"1"
"X1"	"Разъем питания"	"Разъем питания"	"DJK-02B"	"KLS"	"1"
"X2"	"USB разъем тип B"	"Разъем"	"292304-1"	"Te Connectivity"	"1"
"X3"	"Разъем"	"Разъем"	"PBS-6"	""	"1"
"X4, X5"	"Разъем"	"Разъем"	"PBS-8"	""	"2"
"X6"	"Разъем"	"Разъем"	"PBS-10"	""	"1"
"ZQ1"	"Кварцевый резонатор"	"Кварцевый резонатор"	"KX-KT 16.0MHz"	""	"1"
"ZQ2"	"Керамический резонатор"	"Керамический резонатор"	"CSTCE16M0V53-R0"	"Murata"	"1"

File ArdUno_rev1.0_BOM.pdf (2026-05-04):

Designator | ValueType | ValueDescription | ValueManufacturer PartNumber | ValueManufacturer | Quantity
C1 | Конденсатор | 0,1мкФ X7R 10% 0603 SMD | | | | 1
C2 | Конденсатор | 22nФ NP0 5% 0603 SMD | | | | 1
C3 | Конденсатор | 22nФ NP0 5% 0603 SMD | | | | 1
C4 | Конденсатор | 0,1мкФ X7R 10% 0603 SMD | | | | 1
C5 | Конденсатор | 0,1мкФ X7R 10% 0603 SMD | | | | 1
C6 | Конденсатор | н.у.Ф 0603 SMD | | | | 1
C7 | Конденсатор | 1мкФ X7R 10% 0603 SMD | | | | 1
C8 | Конденсатор | 4,7мкФ 20% 0607 SMD | | | | 1
C9 | Конденсатор | 0,1мкФ X7R 10% 0603 SMD | | | | 1
C10 | Конденсатор | 0,1мкФ X7R 10% 0603 SMD | | | | 1
C11 | Конденсатор | 4,7мкФ 20% 0607 SMD | | | | 1
C12 | Конденсатор | 0,1мкФ X7R 10% 0603 SMD | | | | 1
C13 | Конденсатор | 0,1мкФ X7R 10% 0603 SMD | | | | 1
C14 | Конденсатор | 0,1мкФ X7R 10% 0603 SMD | | | | 1
C15 | Конденсатор | 0,1мкФ X7R 10% 0603 SMD | | | | 1
C16 | Конденсатор | н.у.Ф 0603 SMD | | | | 1
C17 | Конденсатор | 0,1мкФ X7R 10% 0603 SMD | | | | 1
C18 | Конденсатор | 0,1мкФ X7R 10% 0603 SMD | | | | 1
DD1 | Операционный уси литель | | LMV358IDR | Texas Instruments | | 1
DD2 | Микроконтроллер | Микроконтроллер | ATMEGA16U2-MU | ATMEGA | | 1
DD3 | Линейный стабили затор напряжения | | LM1117IMPX-5.0 | Texas Instruments | | 1
DD4 | Линейный стабили затор напряжения | | LP2985-33DBVR | Texas Instruments | | 1
DD5 | Микроконтроллер | Микроконтроллер | ATMEGA328P-PU | ATMEGA | | 1
F1 | Предохранитель | | MF-MSMF200-2 | | | 1
HL1 | Светодиод | Светодиод | fyls-0603urc | Foryard | | 1
HL2 | Светодиод | Светодиод | fyls-0603urc | Foryard | | 1
HL3 | Светодиод | Светодиод | fyls-0603urc | Foryard | | 1
HL4 | Светодиод | Светодиод | fyls-0603urc | Foryard | | 1
ICSP1 | Разъем штыревой 2,54 мм | PLD-6 | | | | 1
ICSP2 | Разъем штыревой 2,54 мм | PLD-6 | | | | 1
L1 | Индуктивность | | BLM18AG601SN1D | | | 1
R1 | Резистор | 680Ом 5% 0603 SMD | | | | 1
R2 | Резистор | 10кОм 5% 0603 SMD | | | | 1
R3 | Резистор | 22Ом 1% 0603 SMD | | | | 1
R4 | Резистор | 22Ом 1% 0603 SMD | | | | 1
R5 | Резистор | 10кОм 5% 0603 SMD | | | | 1
R6 | Резистор | 10кОм 5% 0603 SMD | | | | 1
R7 | Резистор | 22Ом 1% 0603 SMD | | | | 1
R8 | Резистор | 1МОм 5% 0603 SMD | | | | 1
R9 | Резистор | 10кОм 5% 0603 SMD | | | | 1
R10 | Резистор | 680Ом 5% 0603 SMD | | | | 1
R11 | Резистор | 0Ом 5% 0603 SMD | | | | 1
R12 | Резистор | 1кОм 1% 0603 SMD | | | | 1
R13 | Резистор | 1кОм 1% 0603 SMD | | | | 1
R14 | Резистор | 680Ом 5% 0603 SMD | | | | 1
R15 | Резистор | 680Ом 5% 0603 SMD | | | | 1
R16 | Резистор | 10кОм 5% 0603 SMD | | | | 1
R17 | Резистор | 1МОм 5% 0603 SMD | | | | 1
R18 | Резистор | 22Ом 1% 0603 SMD | | | | 1
RU1 | Варистор | | CG0603MLC-05E | | | 1
RU2 | Варистор | | CG0603MLC-05E | | | 1
SB1 | Кнопка тактовая | | 2-1437565-7 | Te Connectivity | | 1
VD1 | Диод Шоттки | Диод Шоттки | SS14-E3/61T | Vishay | | 1
VD2 | Диод Шоттки | Диод Шоттки | BAT54HT1G | On Semiconductor | | 1
VD3 | Диод Шоттки | Диод Шоттки | BAT54HT1G | On Semiconductor | | 1
VT1 | MOSFET | | SI2333DDS-T1-GE3 | Vishay | | 1
X1 | Разъем питания | DJK-02B | DJK-02B | KLS | | 1
X2 | USB разъем тип B | | 292304-1 | Te Connectivity | | 1
X3 | Разъем | | | | | 1
X4 | Разъем | | | | | 1
X5 | Разъем | | | | | 1
X6 | Разъем | | | | | 1
ZQ1 | Кварцевый резона тор | | | | | 1
ZQ2 | Керамический рез онатор | | CSTCE16M0V53-R0 | Murata | | 1

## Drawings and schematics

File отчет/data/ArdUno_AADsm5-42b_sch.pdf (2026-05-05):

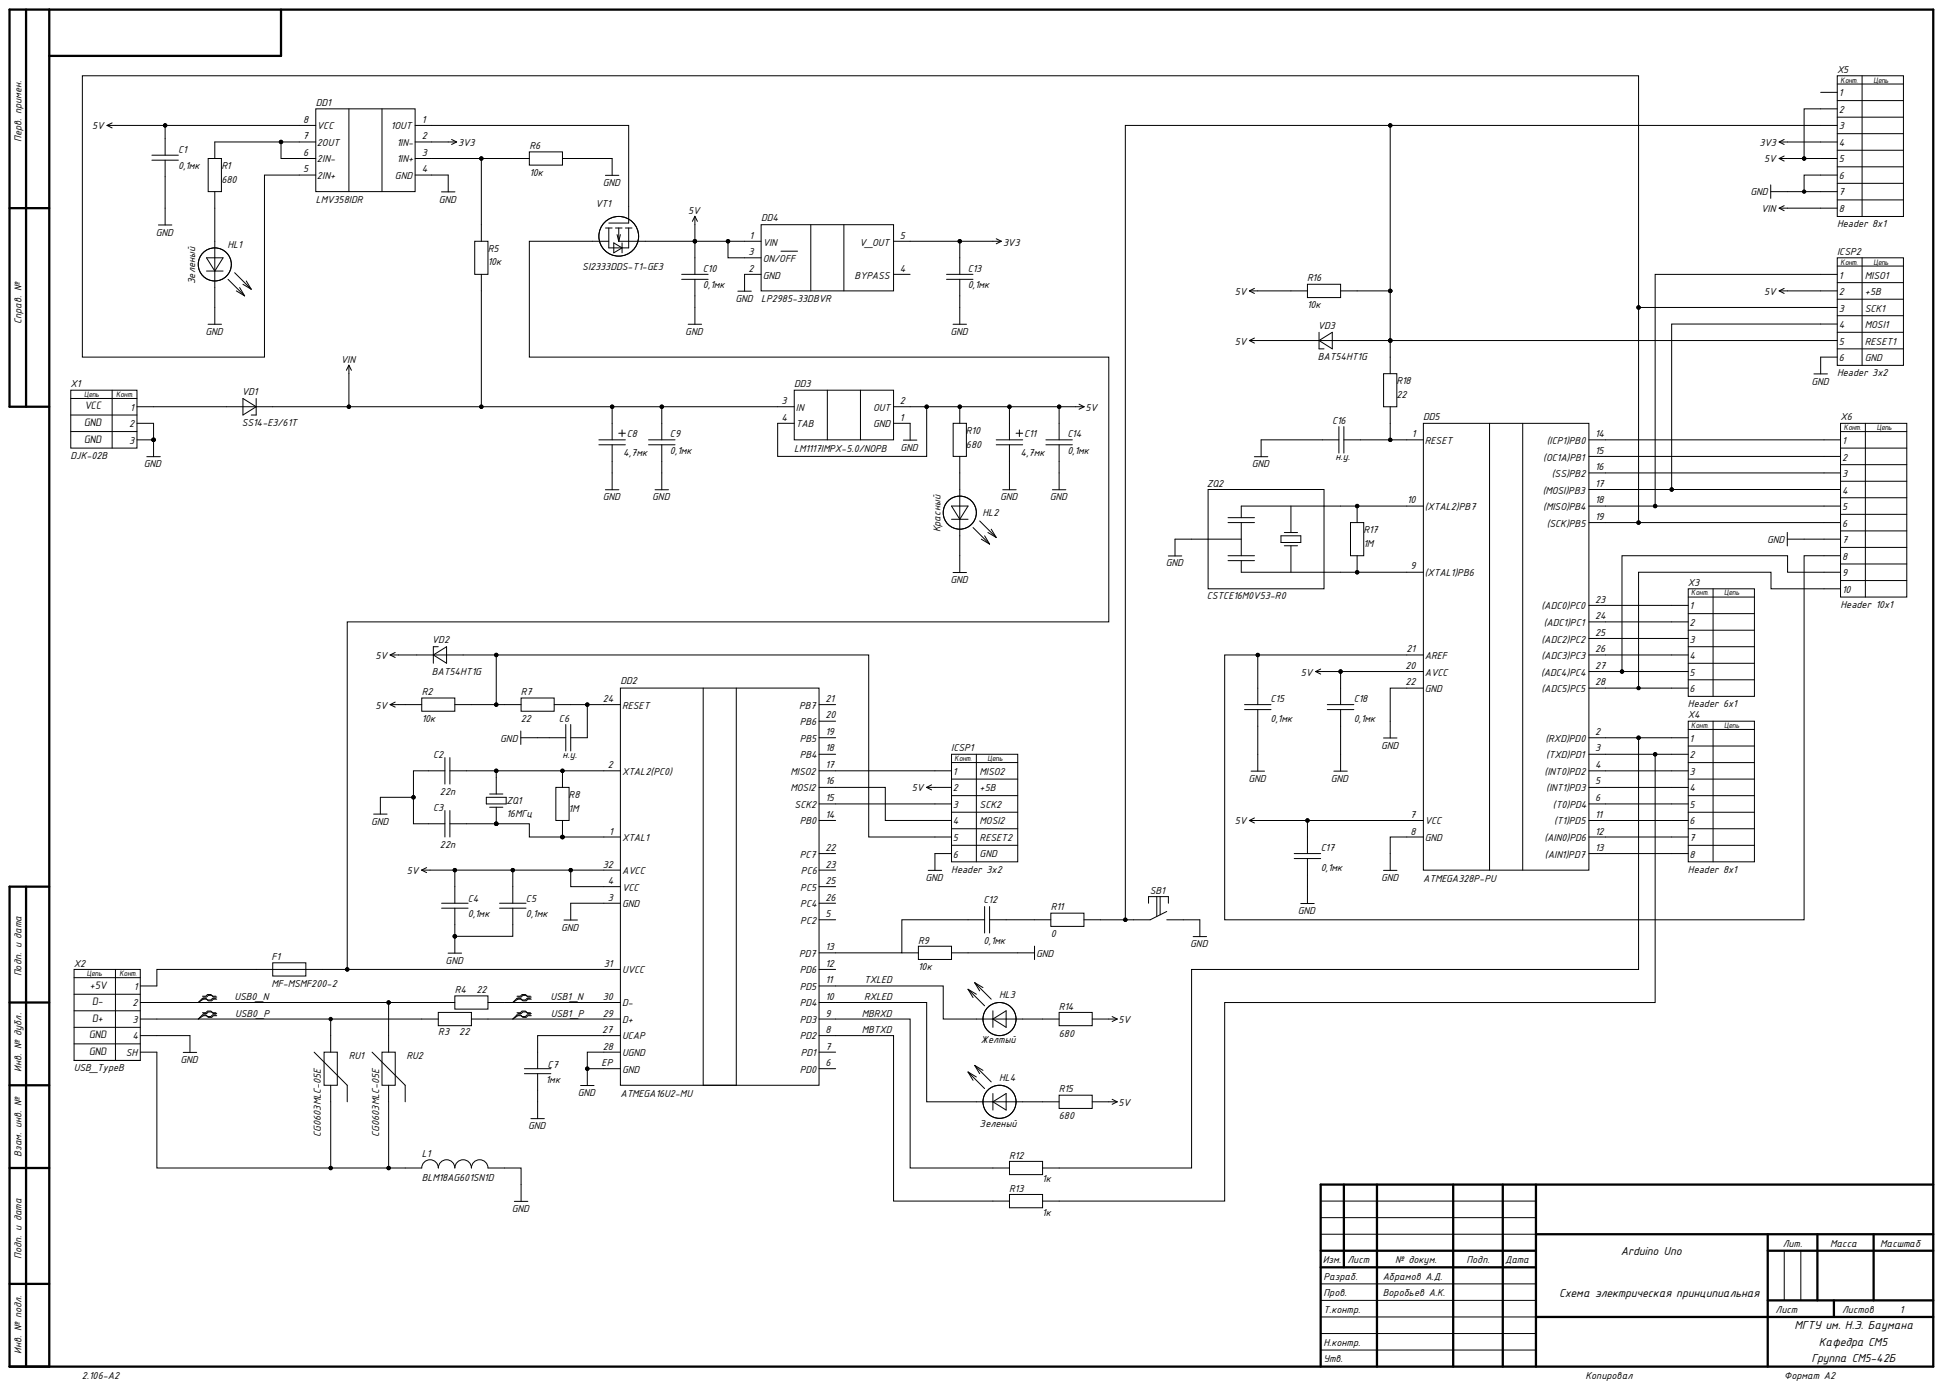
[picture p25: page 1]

Инв. № подл. Инв. № дубл. Подп. и дата Взам. инв. № Подп. и дата Перв. примен. Справ. №

1 | MISO1
2 | +5B

4 | MOSI1
5 | RESET1
6 | GND

VCC | 1
GND | 2

10

(XTAL1)PB6 9

GND 22 | 5

Конт. | Цепь

+5V | 1
D- | 2
D+ | 3

USB0_P | D+ 29 D- 30 | | | MBRXD

UCAP 27 | | MBTXD | Желтый | HL4
UGND 28

GND | SH

Arduino Uno Схема электрическая принципиальная | Лит. | Масса | Масштаб

Изм. | Лист | № докум. | Подп. | Дата
Разраб. | | Абрамов А.Д.
Пров. | | Воробьев А.К.
Т.контр. | | | | | Лист | Листов 1

МГТУ им. Н.Э. Баумана Кафедра СМ5 Группа СМ5-42Б

Н.контр.
Утв.

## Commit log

2026-02-24 initial commit from Altium without bash
    [ArdUno_AADsm5-42b.SchLib]
2026-02-24 finished lab2: added ATMEGA16U2-MU
    [ArdUno_AADsm5-42b.PcbLib, ArdUno_AADsm5-42b.SchLib]
2026-02-25 added resistor, varistor, fuse and condensator
    [ArdUno_AADsm5-42b.PcbLib, ArdUno_AADsm5-42b.SchLib]
2026-02-25 added LEDs
    [ArdUno_AADsm5-42b.PcbLib, ArdUno_AADsm5-42b.SchLib]
2026-02-25 finished lab3: added quartz
    [ArdUno_AADsm5-42b.PcbLib, ArdUno_AADsm5-42b.SchLib]
2026-03-04 added new component, stopped on 8.52 lab4
    [ArdUno_AADsm5-42b.PcbLib, ArdUno_AADsm5-42b.SchLib]
2026-03-07 finally ended lab4
    [ArdUno_AADsm5-42b.PcbLib, ArdUno_AADsm5-42b.SchLib]
2026-03-10 middle commit 9.9.21 lab5
    [ArdUno_AADsm5-42b.SchLib, ArdUno_AADsm5-42b_sch.SchDoc, ArdUno_AADsm5-42b_ver1.1.PrjPcb]
2026-03-11 finished lab5
    [ArdUno_AADsm5-42b.PcbLib, ArdUno_AADsm5-42b.SchLib, ArdUno_AADsm5-42b_sch.SchDoc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]
2026-03-13 beginning lab6
    [ArdUno_AADsm5-42b_pcb.PcbDoc, ArdUno_AADsm5-42b_sch.SchDoc]
2026-03-13 ended lab6
    [ArdUno_AADsm5-42b.PcbLib, ArdUno_AADsm5-42b_pcb.PcbDoc, ArdUno_AADsm5-42b_sch.SchDoc]
2026-04-10 stopped on point 11.5 lab7
    [ArdUno_AADsm5-42b_pcb.PcbDoc, ArdUno_AADsm5-42b_ver1.1.PrjPcb]
2026-04-24 finished lab7
    [ArdUno_AADsm5-42b_pcb.PcbDoc, ArdUno_AADsm5-42b_ver1.1.PrjPcb]
2026-04-29 middle commit page 18/77 lab8
    [ArdUno_AADsm5-42b_pcb.PcbDoc]
2026-04-29 сделал трассировку дорожек, осталось исправить 70+ ошибок
    [ArdUno_AADsm5-42b.PcbLib, ArdUno_AADsm5-42b_pcb.PcbDoc, ArdUno_AADsm5-42b_sch.SchDoc]
2026-04-29 finished optimization distance between connections
    [ArdUno_AADsm5-42b.PcbLib, ArdUno_AADsm5-42b_pcb.PcbDoc]
2026-04-29 stopped on 12.14 lab8 (page 52/77)
    [ArdUno_AADsm5-42b_pcb.PcbDoc]
2026-04-30 finished lab8
    [ArdUno_AADsm5-42b.PcbLib, ArdUno_AADsm5-42b_ver1.1.PrjPcb]
2026-05-04 fixed connectors on bottom layer and added gerber files
2026-05-04 added gerber files, schematic pdf and etc
    [ArdUno_AADsm5-42b_sch.SchDoc, ArdUno_AADsm5-42b_ver1.1.PrjPcb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]
2026-05-04 исправления в менеджере параметров и добавление списка компонентов по ГОСТ
    [ArdUno_AADsm5-42b_sch.SchDoc, ArdUno_AADsm5-42b_ver1.1.PrjPcb, ArdUno_rev1.0_BOM.csv]
2026-05-05 добавил папку для отчета и туда скрины бахнул
    [ArdUno_AADsm5-42b_sch.SchDoc, ArdUno_AADsm5-42b_ver1.1.PrjPcb]
2026-05-13 отчет бахнул
    [ArdUno_AADsm5-42b.PcbLib]
